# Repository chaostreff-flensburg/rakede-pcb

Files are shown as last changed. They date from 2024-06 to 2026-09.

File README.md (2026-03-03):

# ctfl-rakete-pcb

Converting this sticker desing into a PCB that lights up its flame and lighthouse top from the bottom side using some LEDs and a coin cell battery.

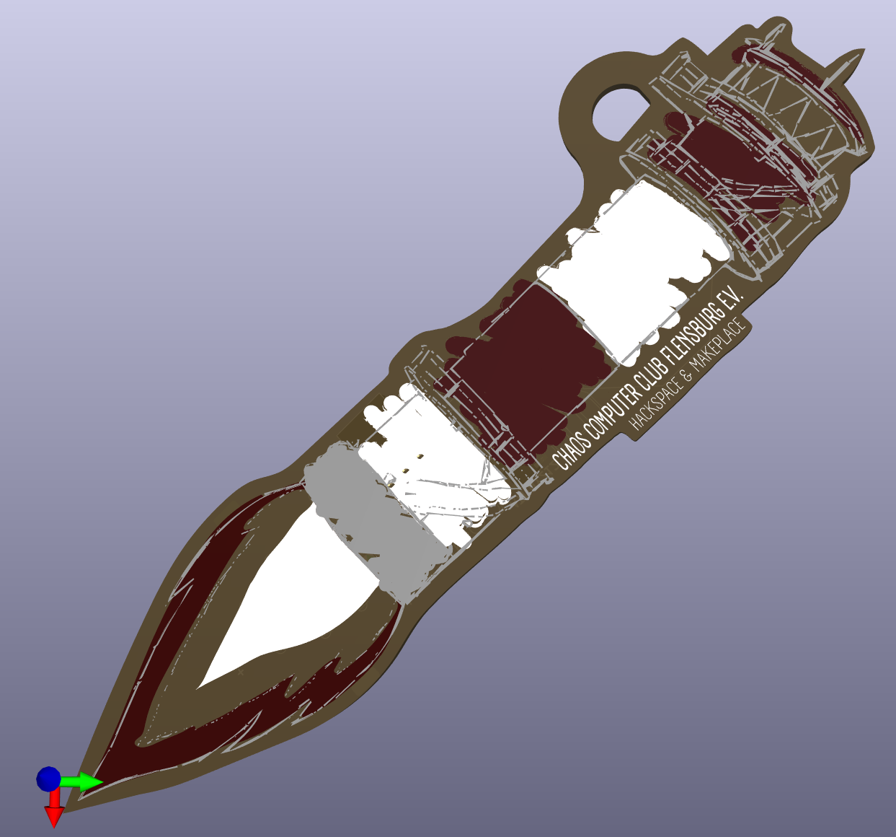
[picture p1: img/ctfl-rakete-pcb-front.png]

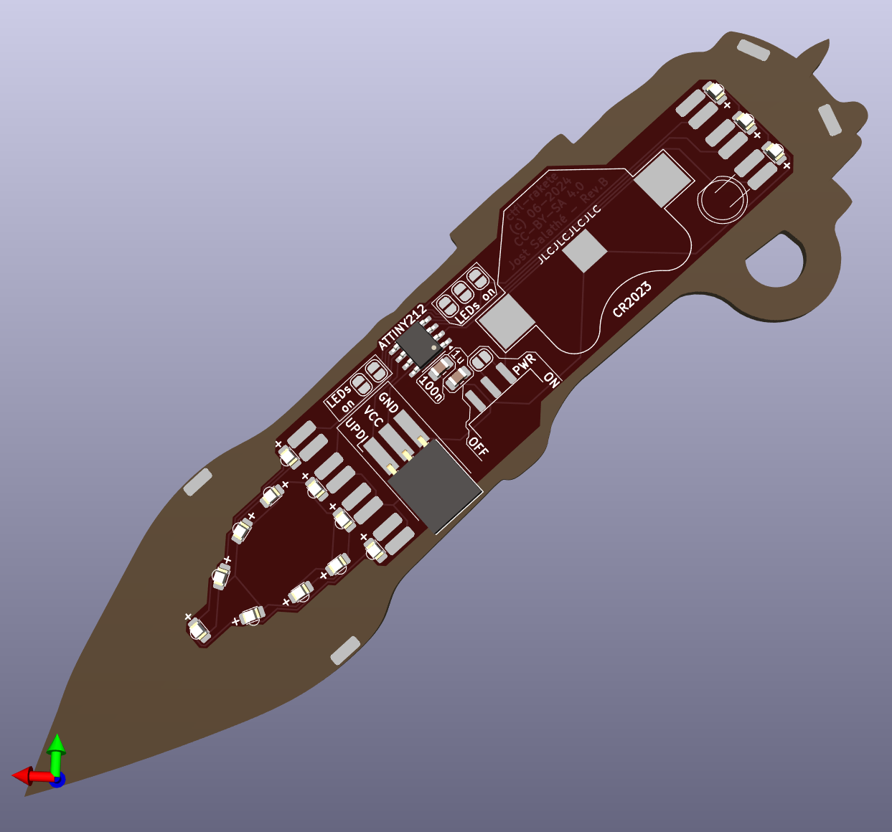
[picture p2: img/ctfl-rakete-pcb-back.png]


## Implementing the colors

Produce the PCBs with **red solder mask** and **white Silkscreen**.

| color | objects | pcb layers present | notes |
| --- | --- | --- | --- |
| white | background |  | considering the background to be transparent |
| white | w_flame | F.Cu, F.Silkscreen |  |
| yellow | y_flame, y_light | none | blank FR4 should give a nice translucent yellow |
| red | r_flame | F.Mask | only red solder mask should give a nice translucent red |
| red | r_tower, r_top, r_roof | F.Mask, f.Cu | with the copper underneath, the red solder mask should appear darker than at the flame |
| light grey | w_base, w_tower | F.Cu, F.Silkscreen |  |
| dark grey | g_base | F.Cu | not differentiated from black outlines |
| black | b_contours, b_name | F.Cu, F.Mask | only copper coated with tin should give a nice contouring contrast |

### Extracting solder mask geometry (F.Mask) from the complete SVG file

In KiCAD the solder mask is expressed as an exclusion mask from the usually all present solder mask coverage.
Meaning that you define geometry where you want solder mask NOT to be.

So the gemonetry we import into KiCAD has to be the negative of the red parts of our logo.

Additionally the solder mask has to back up the silkscreen so that negative image also has to include our white parts.

I concrete terms we need to perform the following steps on our yource vector grapfics to get the desired F.Mask geometry:
1. Delete the yellow lighthous part at the top because it is clipped by all surrounding parts and itself does not clip any other.
1. Combine the white and the red flame part into one.
1. Subtract the yellow flame part from the formerly combined rest of the flame.
1. Also subtract the dark grey socket part from the remaining flame.
1. Combine all remaining red and white parts.
1. Subtract the black outlines which shall poke through the solder mask and the silk screen. Now we have our positive image of the solder mask we want (plus the outline which we also want for positioning).
1. Duplicate the outline and move the duplicate below our solder mask positive.
1. Subtract the positive from the duplicate of the outline.
1. Save as new SVG file (`F.Mask.svg`)
1. Now you can import the SVG file to the appropriate layer in the pcb layout while scaling it by **1.85**.

## Part sourcing

| cnt THT | cnt THT-uC | cnt SMD | reference | title | reichelt.de | mouser.de |
| --- | --- | --- | --- | --- | --- | --- |
| 1 | 1 | 1 | BT1 | battery clip | [KZH 20SMD](https://www.reichelt.de/knopfzellenclip-fuer-20-mm-smd-kzh-20smd-p56574.html) | [534-3034](https://www.mouser.de/ProductDetail/Keystone-Electronics/3034?qs=LDXARy4xNQtGYr6pIAv90A%3D%3D) |
| 1 | 1 | 1 | SW1 | power switch | [SS SMD402](https://www.reichelt.de/schiebeschalter-1x-um-liegend-smd-ss-smd402-p112181.html) | [MSS-102545-14A-V-SMT](https://www.mouser.de/ProductDetail/CUI-Devices/MSS-102545-14A-V-SMT?qs=DRkmTr78QARl%2FtwuH8uRQg%3D%3D) |
| 0 | 1 | 1 | U1 | microcontroller | [ATTINY212](https://www.reichelt.de/8-bit-attiny-avr-risc-mikrocontroller-2-kb-20-mhz-soic-8-attiny212-ssn-p335520.html) | [ATTINY212-SSN](https://www.mouser.de/ProductDetail/Microchip-Technology/ATTINY212-SSN?qs=3HJ2avRr9PJX8cJeG3zkDw%3D%3D) |
| 0 | 0 | 14 | D? | SMD LEDs | - | [859-LTW-220DS5](https://www.mouser.de/ProductDetail/Lite-On/LTW-220DS5?qs=xb8aMrBSZRKaoLOPaZYE%252BQ%3D%3D) or [XIASONGXIN LIGHT - Side SMD 0805 (choose warm white)](https://de.aliexpress.com/item/32890300371.html) |
| 7 | 7 | 0 | D? | 5mm LEDs | [EVERLIGHT 334-15/X1C5-6QSA/EU](https://www.reichelt.de/led-5-mm-bedrahtet-warmweiss-7150-mcd-50--led-el-5-7150ww-p164207.html) | [941-C512AWNSCZ0B0152](https://www.mouser.de/ProductDetail/Cree-LED/C512A-WNS-CZ0B0152?qs=xEJ61ozf1a3Ja%252B55bf1fHw%3D%3D) |
| 0 | 1 | 1 | J1 | programming header (break off 3 of 50) | - | [437-8018305040001101](https://www.mouser.de/ProductDetail/Preci-dip/801-83-050-40-001101?qs=KBM%2FMdeLKegYqxBCoh54QQ%3D%3D) |
| 0 | 1 | 1 | C1 | 0805 capacitor 100 nF | - | [80-C0805C104J5R](https://www.mouser.de/ProductDetail/KEMET/C0805C104J5RACTU?qs=gbgtKHXraGH15GhoNPXHBg%3D%3D) |
| 0 | 1 | 1 | C3 | 0805 capacitor 1 uF | - | [963-UMK212B7105KG-T](https://www.mouser.de/ProductDetail/TAIYO-YUDEN/UMK212B7105KG-T?qs=PzICbMaShUdi76GLXMVYcA%3D%3D) |

## Default firmware

The directory `defaultFirmware` holds an Arduino sketch that is meant to be used with the [megaTinyCore](https://github.com/SpenceKonde/megaTinyCore) board support package for Arduino and can then be uploaded using a programmer like [SerialUPDI](https://github.com/wagiminator/AVR-Programmer/tree/master/SerialUPDI_Programmer), e.g. the [Adafruit UPDI Friend](https://learn.adafruit.com/adafruit-updi-friend).

Make sure to select the correct Chip in Arduino under `Tools -> Chip -> ATtiny212`, the correct Programmer under `Tools -> Programmer -> SerialUPDI - 230400 baud` (probably, depending on what you have) as well as the correct clock source under `Tools -> Clock -> "5 MHz internal"`

The logo on the PCB and the blinking pattern are based on the [lighthouse Kalkgrund](https://www.deutsche-leuchtfeuer.de/ostsee/kalkgrund.html).

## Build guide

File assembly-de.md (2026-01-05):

# Allgemeine Tips

## Ein Anschluss nach dem Anderen

Es bietet sich an, bei jedem Bauteil folgendermaßen vorzugehen:
- Erst ein einzelnes Lötpad für dieses Bautie vor-verzinnen
  - Dafür die Spitze des Lötkolbens mit etwas Druck so an die zu verzinnende Fläche legen, dass noch genug Platz ist, um das Lot direkt zum heißen Lötpad zu führen
- Das Bauteil (bei Bedarf mit einer Pinzette) korrekt positionieren, sodass der eine Anschluss in dem frisch aufgebrachten Lot sitzt
- Den Lötkolben wegziehen und das Bauteil noch einen Augenblick fixieren, bis das Lot erkalet ist.

So kann jetzt noch, falls erforderlich, die Position des Bauteils an dieser einen Lötstelle korrigiert werden.

Bist du mit dem Sitz des Bauteils auf dem zugehörigen Footbrint zufrieden, verlötest du den/die übrigen Anschluss(-üsse) des Bauteils.

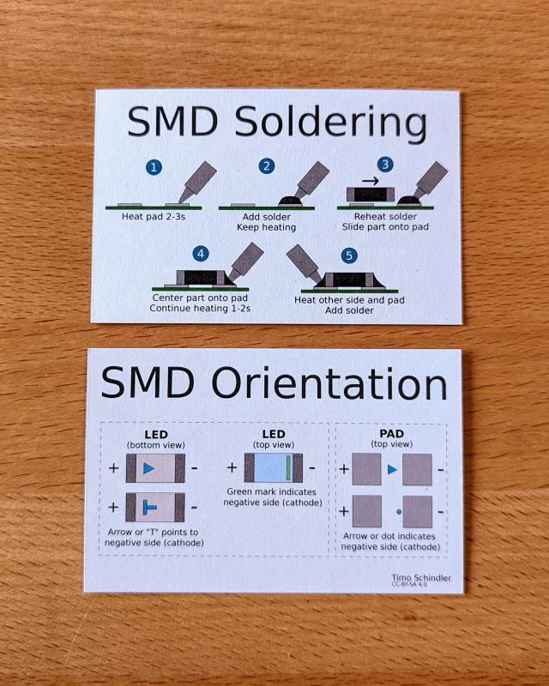
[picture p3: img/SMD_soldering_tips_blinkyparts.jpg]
SMD Löttips von von Blinkyparts


## Von Klein nach Groß und/oder von Innen nach Außen

Arbeite von innen nach außen und von kleinen Bauteilen zu großen. Es mag zwar verlockend sein, mit den großen, einfach zu lötenden Teilen anzufangen, aber üblicherweise sind sie dir dann später im Weg.

# Schwierigkeitsgrad 1: Mit Beinchen

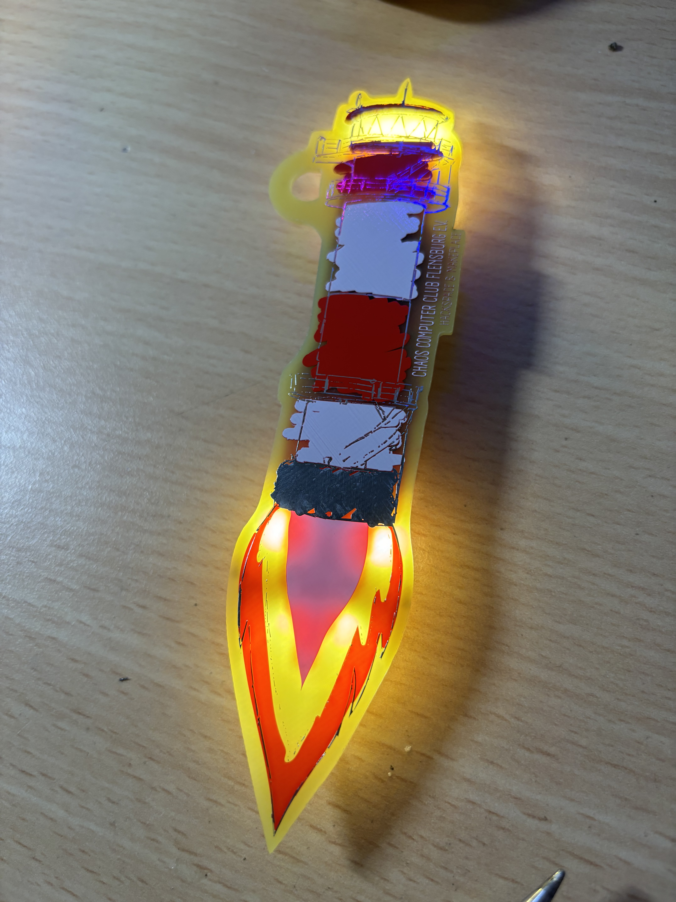
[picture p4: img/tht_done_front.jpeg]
fertig


## Benötigte Bauteile

In empfohlener Bestückreihenfolge sortiert:

| Nummer | Anzahl |Name |
| --- | --- | --- |
| 1 | 1 | Platine |
| 2 | 1 | Schalter |
| 3 | 1 | Batteriehalter |
| 4 | 7 | weiße 5mm LED (ca. 3V)  |
| 5 | 1 | CR2032 Knopfzellenbatterie |

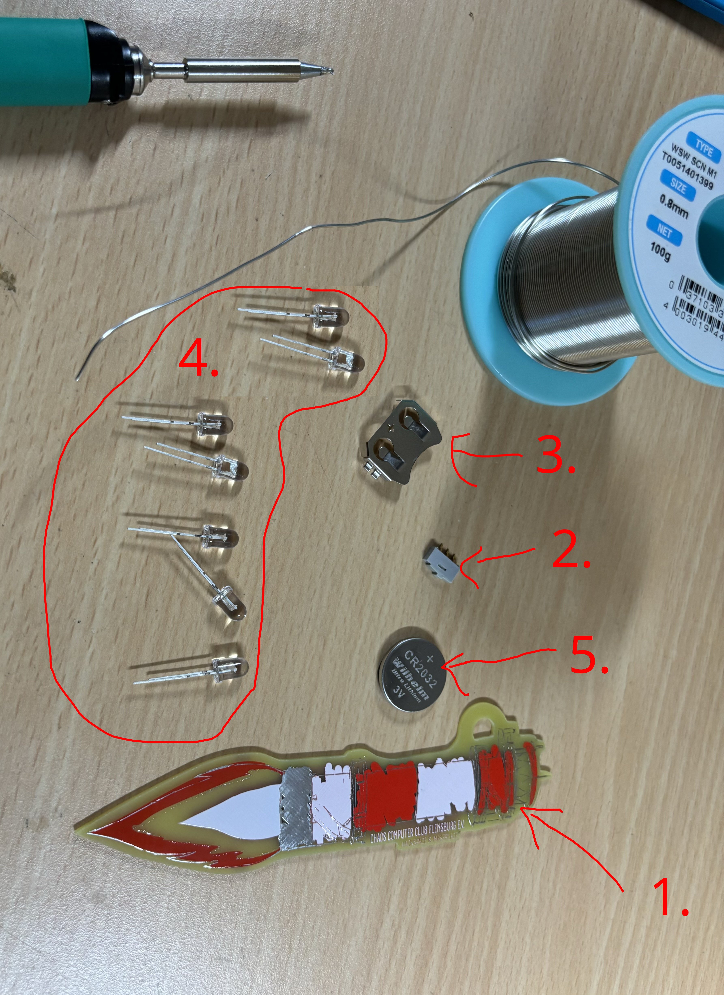
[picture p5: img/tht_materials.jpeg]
THT Material


## Montage

Solange die Platine noch so schön leer ist, können die 5 Lötbrücken geschlossen werden, die die LEDs dauerhaft leuchten lassen, solange der Schalter an ist. Sie sind markiert mit der Beschriftung "LEDs on".

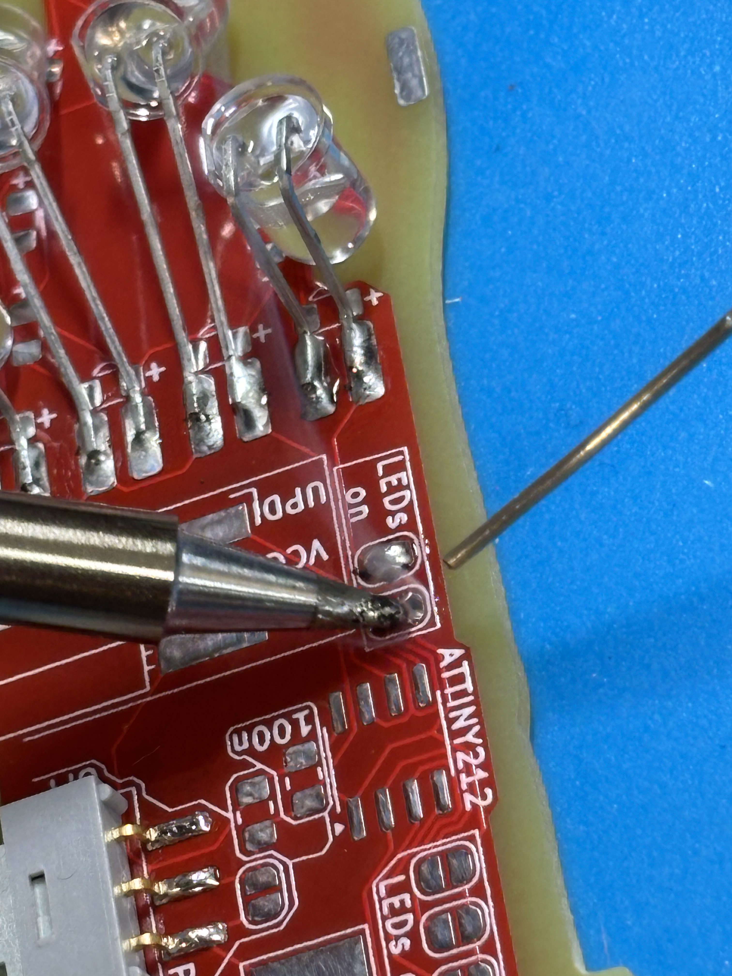
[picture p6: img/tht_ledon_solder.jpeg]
Lötbrücken


Als erstes Bauteil sollte bei dieser Variante der Schalter montiert werden.

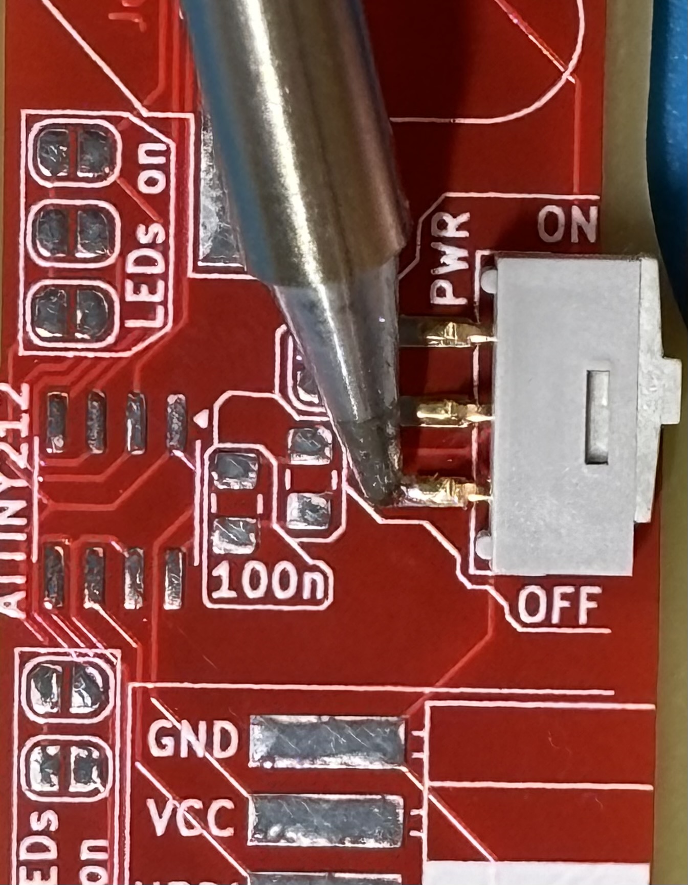
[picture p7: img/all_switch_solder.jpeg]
Schalter


Damit die Knopfzelle guten Kontakt hat, sollte noch etwas Zinn auf den negativen Batteriekontakt auf der Platine gegeben werden. Aber auch nicht zu viel, sonst sitzt die Batterie nachher zu stramm.

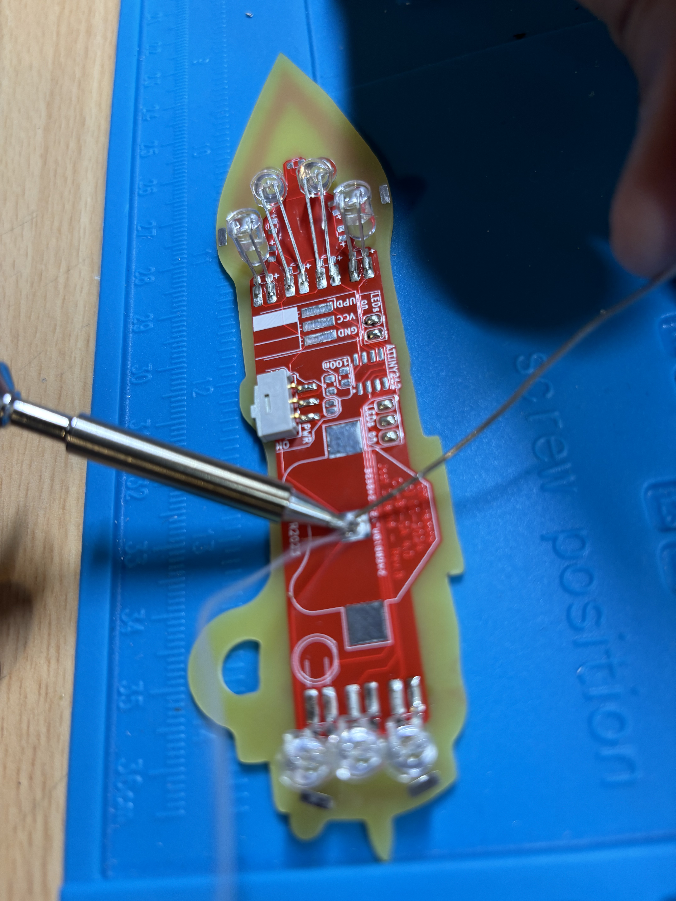
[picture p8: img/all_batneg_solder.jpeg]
Batteriekontakt Minus


Danach kann der Batteriehalter dadrübergelötet werden. Hierbei am besten die beiden Verbindungen zwischen Lötpads und Batteriehalter richtig mit Zinn fluten, damit die mechanische Klemmkraft der Batterie den Halter später nicht abreißt.

Auf dem folgenden Bild sind die Stellen etwas zu sparsam ausgestattet:

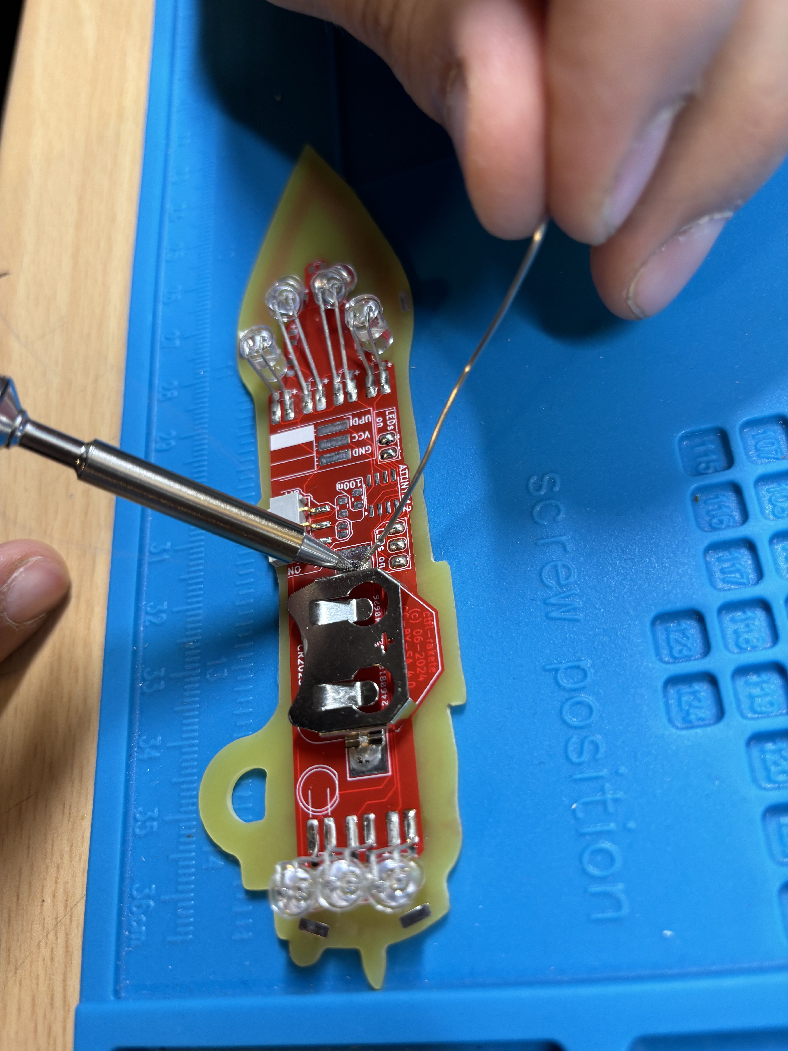
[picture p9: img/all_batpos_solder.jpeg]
Batteriehalter


Jetzt gibt es Interpretationsspielraum, wie du die LEDs am liebsten montieren magst.

Hauptsache ist, dass du die beiden Beinchen richtig verbindest.

Das längere Beinchen ist Plus (auf der Platine mit "+" markiert), das kürzere Beinchen Minus. Aber selbst nachdem du die Beinchen gekürzt hast, kannst du das noch zuordnen, weil das Gehäuse der LED an der Minusseite etwas abgeflacht ist.

Wenn du eine LED falsch herum einbaust, leuchtet sie einfach nicht. Versuche dann, sie andersherum einzubauen.

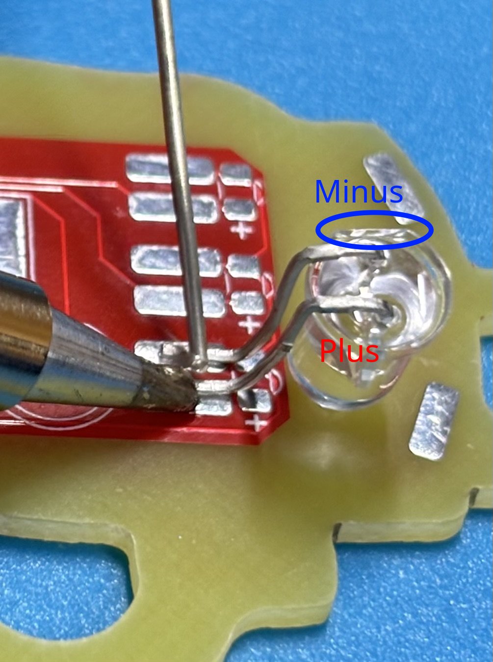
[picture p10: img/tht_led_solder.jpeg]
LED verlöten


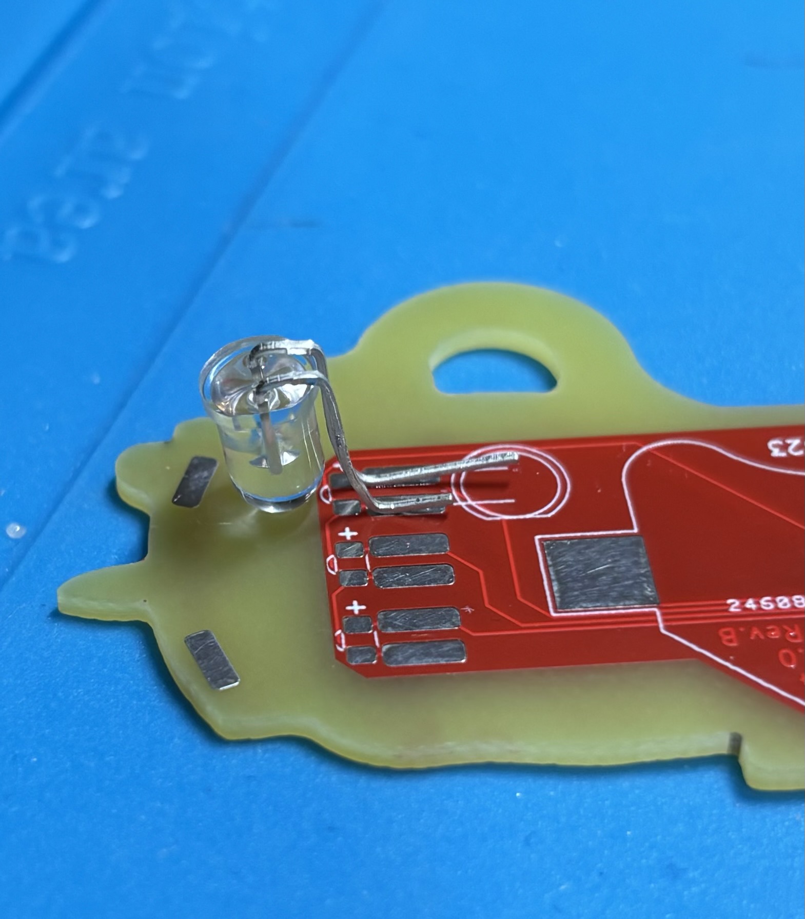
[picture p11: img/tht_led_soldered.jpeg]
LED verlötet


So könnten das dann zum Beispiel aussehen:

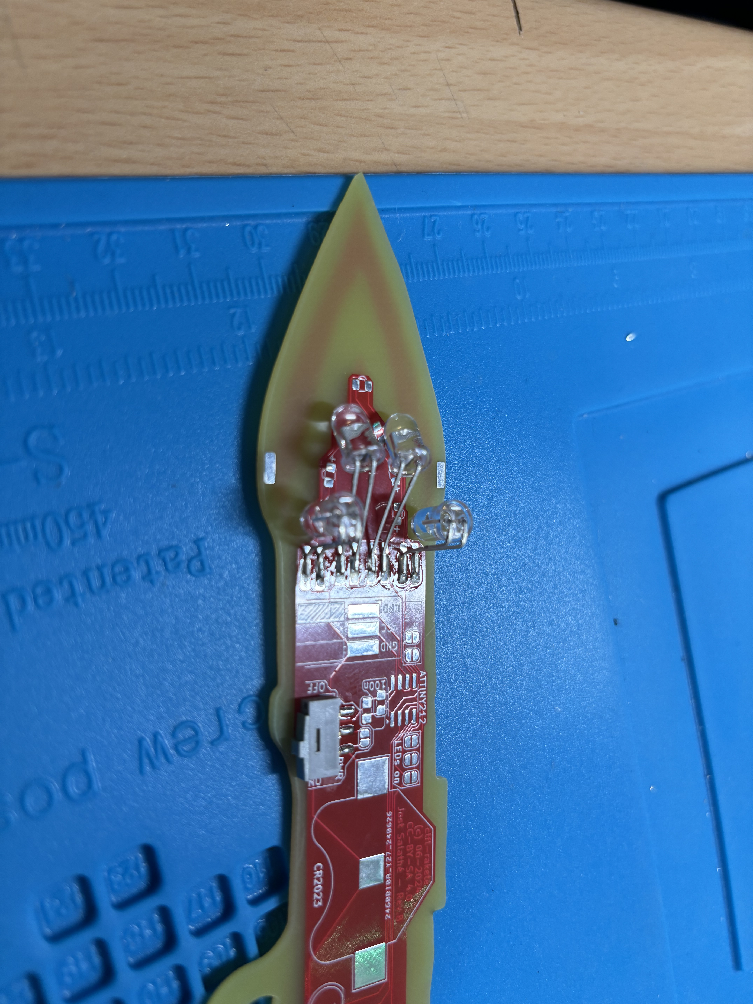
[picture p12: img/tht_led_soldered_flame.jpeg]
LEDs Flamme verlötet


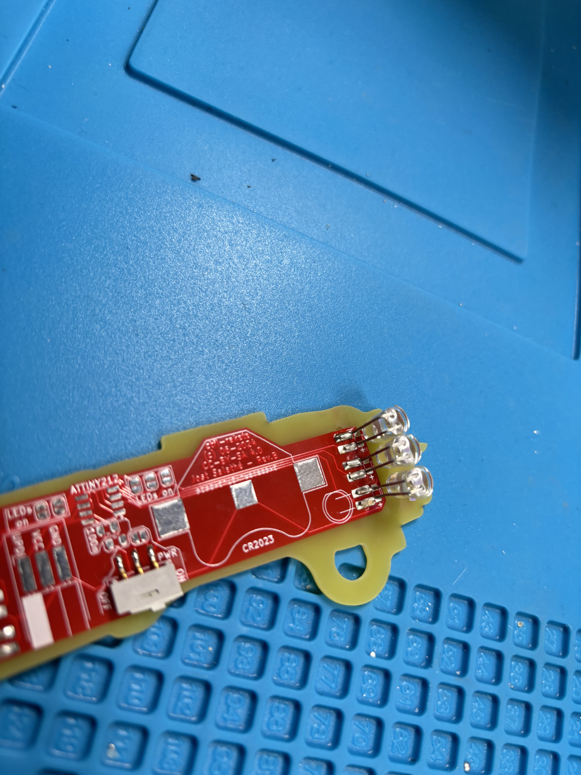
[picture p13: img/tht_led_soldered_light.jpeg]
LEDs oben verlötet


# Schwierigkeitsgrad 2: Mit Beinchen und Mircocontroller

## Benötigte Bauteile

In empfohlener Bestückreihenfolge sortiert:

| Nummer | Anzahl |Name |
| --- | --- | --- |
| 1 | 1 | Platine |
| 2 | 1 | Entkoppelkondensator 100 nF |
| 3 | 1 | Stützkondensator 1 uF |
| 1 | 1 | ATtiny212 Mircocontroller |
| 5 | 1 | Schalter |
| 6 | 1 | Programmieranschluss (UPDI) |
| 7 | 1 | Batteriehalter |
| 8 | 7 | weiße 5mm LED (ca. 3V)  |
| 9 | 1 | CR2032 Knopfzellenbatterie |

SMTHT Material

## Montagehinweise

Zur Montage des Schwierigkeitsgrads 1 ändert sich folgendes:
- Es wird zusätzlich ein Microcontroller mit ein paar Hilfsbauteilen aufgelötet
  - 2 SMD-Kondensatoren zur Stabilisierung der Controllerversorgung
  - Programmieranschluss
- Die 5 Lötbrücken werden nicht gesetzt - ihre Aufgabe wird von dem Microcontroller übernommen

Die Orientierung des Microcontrollers sollte unbedingt beachtet werden.
Auf dem Controllergehäuse ist ein Punkt bei Pin 1.
Passend dazu ist auf der Platine an Pin 1 ein kleiner Pfeil.

ATTINY orientation

Die beiden Kondensatoren sind parallel geschaltet und dienen nur zur Stabilisierung der Versorgungsspannung des Microcontrollers.
Es ist nicht so wichtig, welcher von beiden wo sitzt.
Und falls einer oder beide verloren gehen, ist das auch nicht so schlimm.

# Schwierigkeitsgrad 3: Beinfrei

## Benötigte Bauteile

In empfohlener Bestückreihenfolge sortiert:

| Nummer | Anzahl |Name |
| --- | --- | --- |
| 1 |  1 | Platine |
| 2 |  1 | Entkoppelkondensator 100 nF |
| 3 |  1 | Stützkondensator 1 uF |
| 1 |  1 | ATtiny212 Mircocontroller |
| 5 |  1 | Schalter |
| 6 |  1 | Programmieranschluss (UPDI) |
| 7 | 14 | weiße SMD-LEDs (seitenleuchtend, ca. 3V)  |
| 8 |  1 | Batteriehalter |
| 9 |  1 | CR2032 Knopfzellenbatterie |

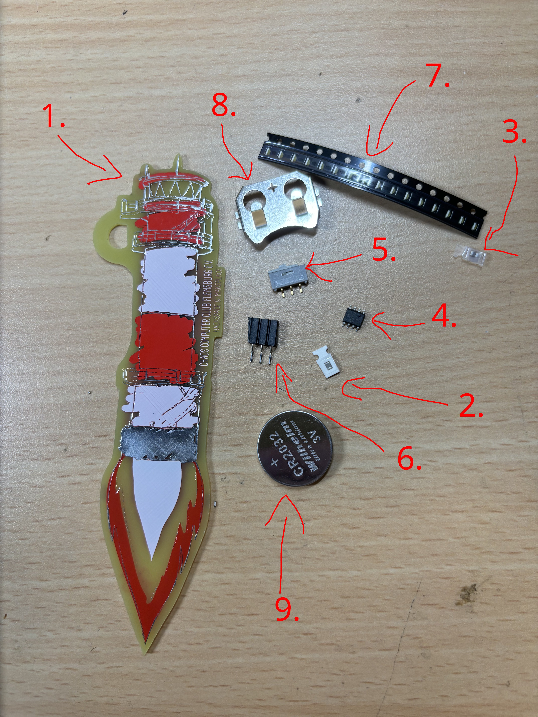
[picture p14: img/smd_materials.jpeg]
SMD Material


## Montagehinweise

Zur Montage des Schwierigkeitsgrads 2 ändert sich folgendes:
- die 7 5mm LEDs werden ersetzt durch 14 zur Seite leuchtende SMD-LEDs

Die Polarität der LEDs ist dabei unbedingt zu beachten:

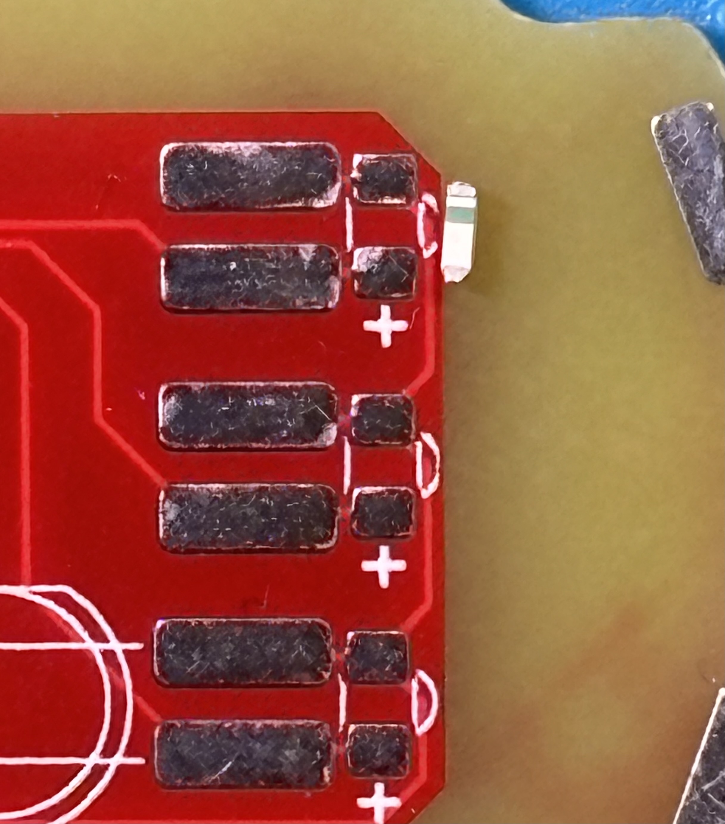
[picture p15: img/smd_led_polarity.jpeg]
SMD-LED Polarität


Verwende am besten eine Pinzette, um die LED in Position zu halten, während du die erste Seite festlötest:

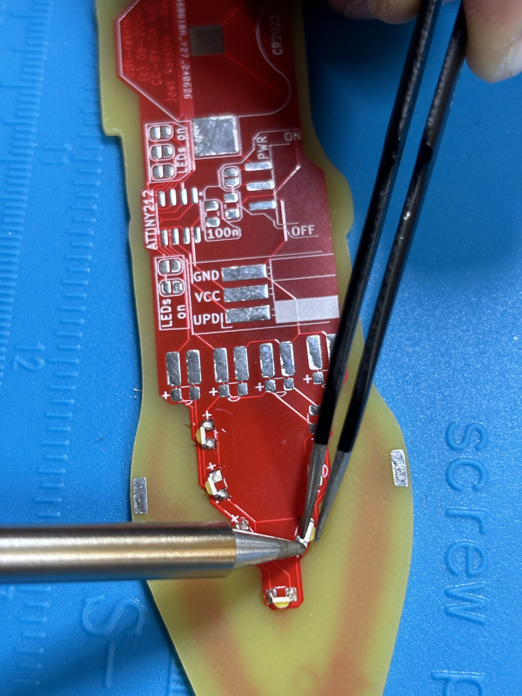
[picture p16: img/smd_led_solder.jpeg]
SMD-LED festlöten


Es werden 14 LEDs benötigt.
Da die kleinen LEDs leicht einmal verloren gehen, legen wir den Kits normalerweise 16 LEDs bei.

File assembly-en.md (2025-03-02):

# TBD

See [german version](assembly-de.md)...

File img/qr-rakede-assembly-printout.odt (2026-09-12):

How to solder the C3FL Rakede PCB

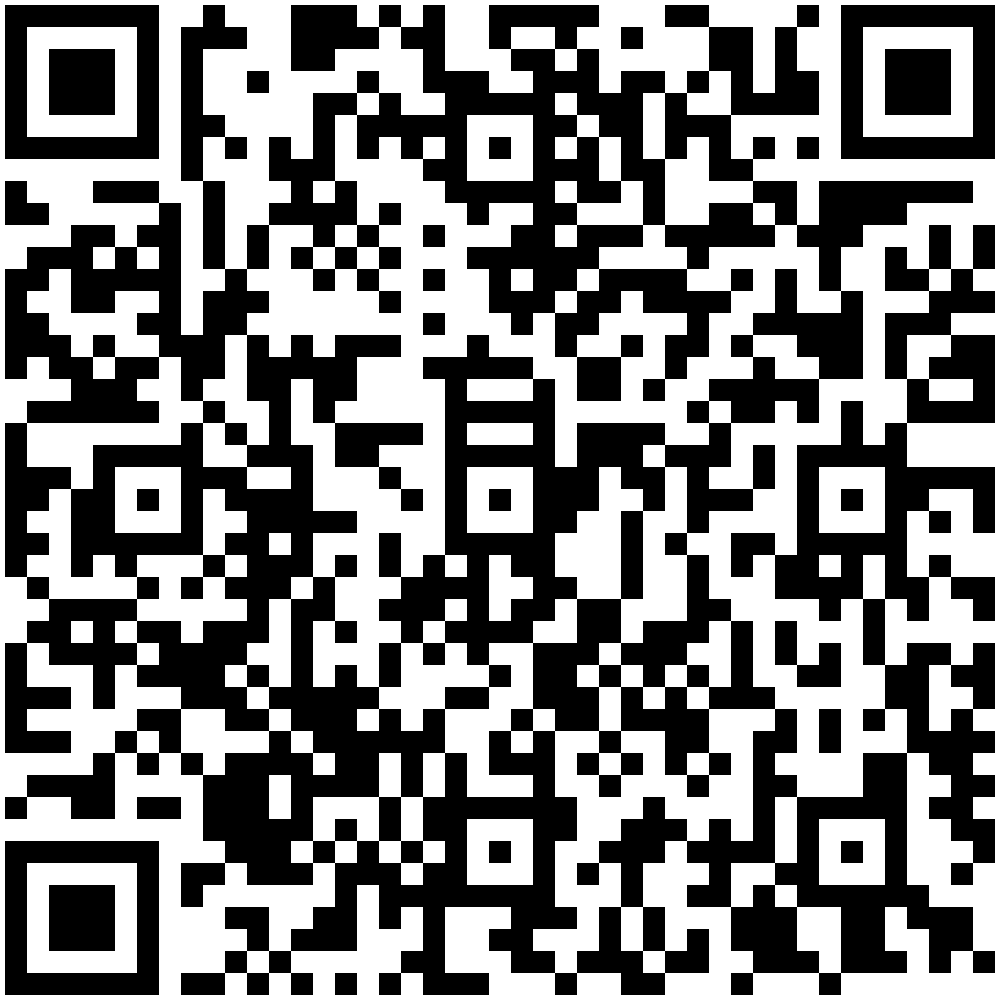
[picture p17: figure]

Wie man die C3FL Rakede PCB löded

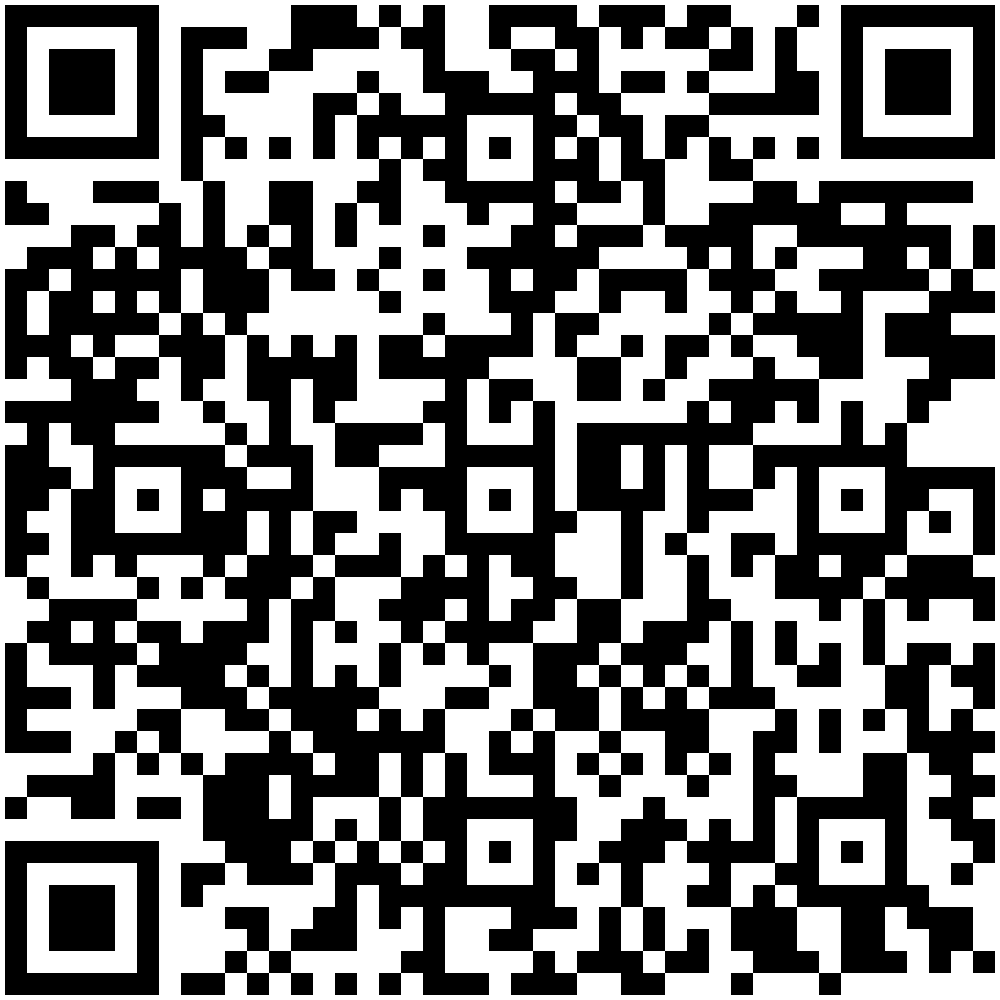
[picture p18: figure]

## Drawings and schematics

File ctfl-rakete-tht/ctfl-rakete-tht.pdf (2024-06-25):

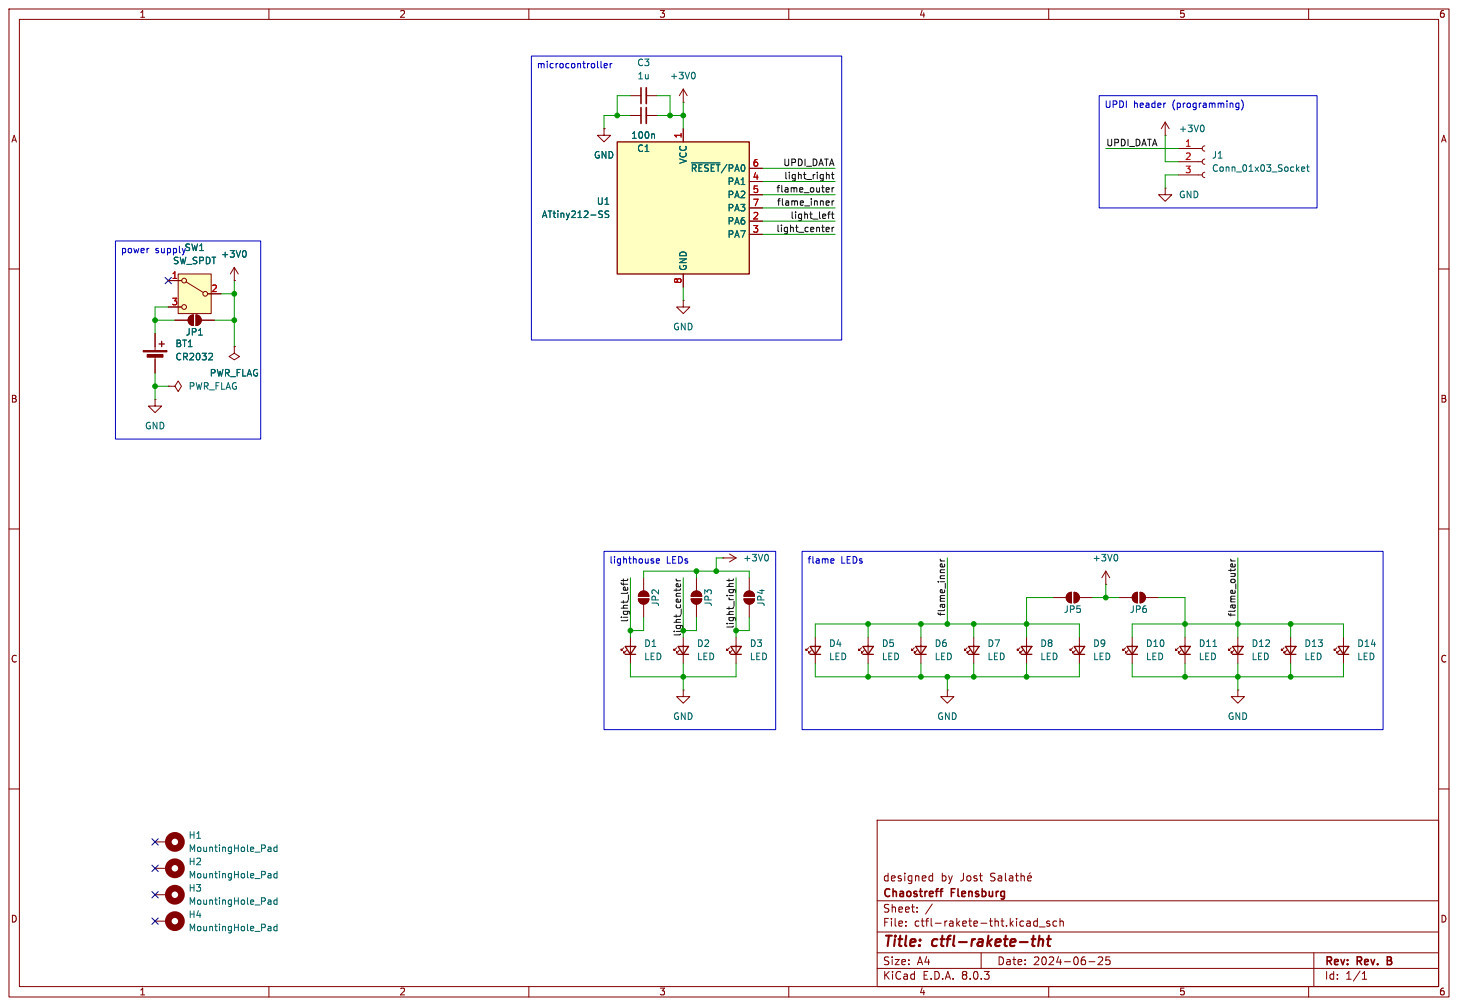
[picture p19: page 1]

flame LEDs power supply

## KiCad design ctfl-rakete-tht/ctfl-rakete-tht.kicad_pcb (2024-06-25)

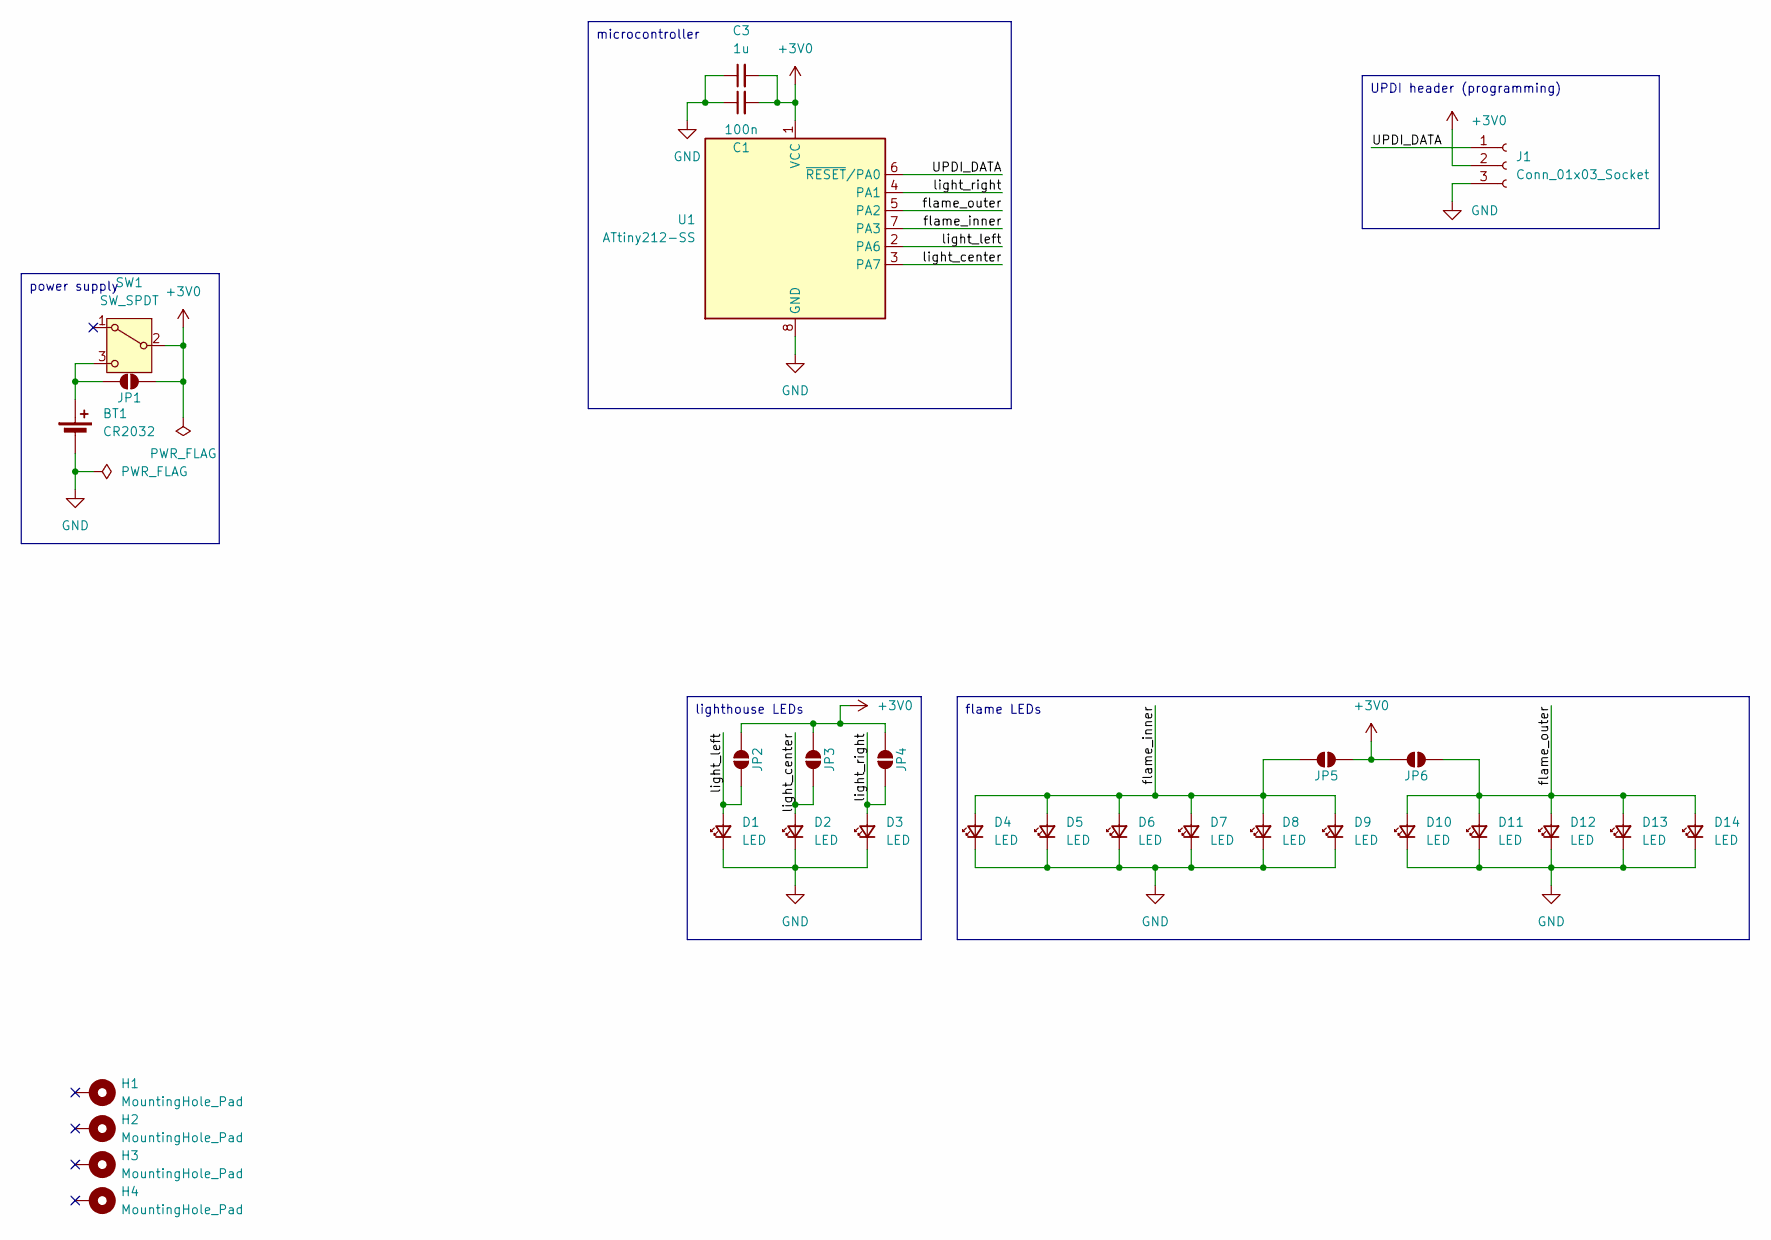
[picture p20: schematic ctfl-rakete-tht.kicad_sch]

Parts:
BT1: CR2032; BatteryHolder_Multicomp_BC-2001_1x2032
C1: 100n; C_0805_2012Metric_Pad1.18x1.45mm_HandSolder
C3: 1u; C_0805_2012Metric_Pad1.18x1.45mm_HandSolder
D1, D2, D3, D4, D5, D10, D11: LED; LED_combo_0805_5mmSMD_HandSolder
D6, D7, D8, D9, D12, D13, D14: LED; LED_0805_SMD_HandSolder
H1, H2, H3, H4: MountingHole_Pad; wire_pad
J1: Conn_01x03_Socket; PinSocket_1x03_P2.54mm_Horizontal_SMD
JP1, JP2, JP3, JP4, JP5, JP6: SolderJumper_2_Open; SolderJumper-2_P1.3mm_Open_RoundedPad1.0x1.5mm
SW1: SW_SPDT; SW_SPDT_ESP4020
U1: ATtiny212-SS; SOIC-8_3.9x4.9mm_P1.27mm

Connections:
+3V0: C1.2, C3.2, J1.2, JP1.2 (B), JP2.2 (B), JP3.2 (B), JP4.2 (B), JP5.2 (B), JP6.2 (B), SW1.2 (B), U1.1 (VCC)
/UPDI_DATA: J1.1, U1.6 (~RESET/PA0)
/flame_inner: D4.2 (A), D5.2 (A), D6.2 (A), D7.2 (A), D8.2 (A), D9.2 (A), JP5.1 (A), U1.7 (PA3)
/flame_outer: D10.2 (A), D11.2 (A), D12.2 (A), D13.2 (A), D14.2 (A), JP6.1 (A), U1.5 (PA2)
/light_center: D2.2 (A), JP3.1 (A), U1.3 (PA7)
/light_left: D1.2 (A), JP2.1 (A), U1.2 (PA6)
/light_right: D3.2 (A), JP4.1 (A), U1.4 (PA1)
GND: BT1.2 (-), C1.1, C3.1, D1.1 (K), D2.1 (K), D3.1 (K), D4.1 (K), D5.1 (K), D6.1 (K), D7.1 (K), D8.1 (K), D9.1 (K), D10.1 (K), D11.1 (K), D12.1 (K), D13.1 (K), D14.1 (K), J1.3, U1.8 (GND)
unnamed: BT1.1 (+), JP1.1 (A), SW1.3 (C)

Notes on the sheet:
flame LEDs
UPDI header (programming)
microcontroller
lighthouse LEDs
power supply

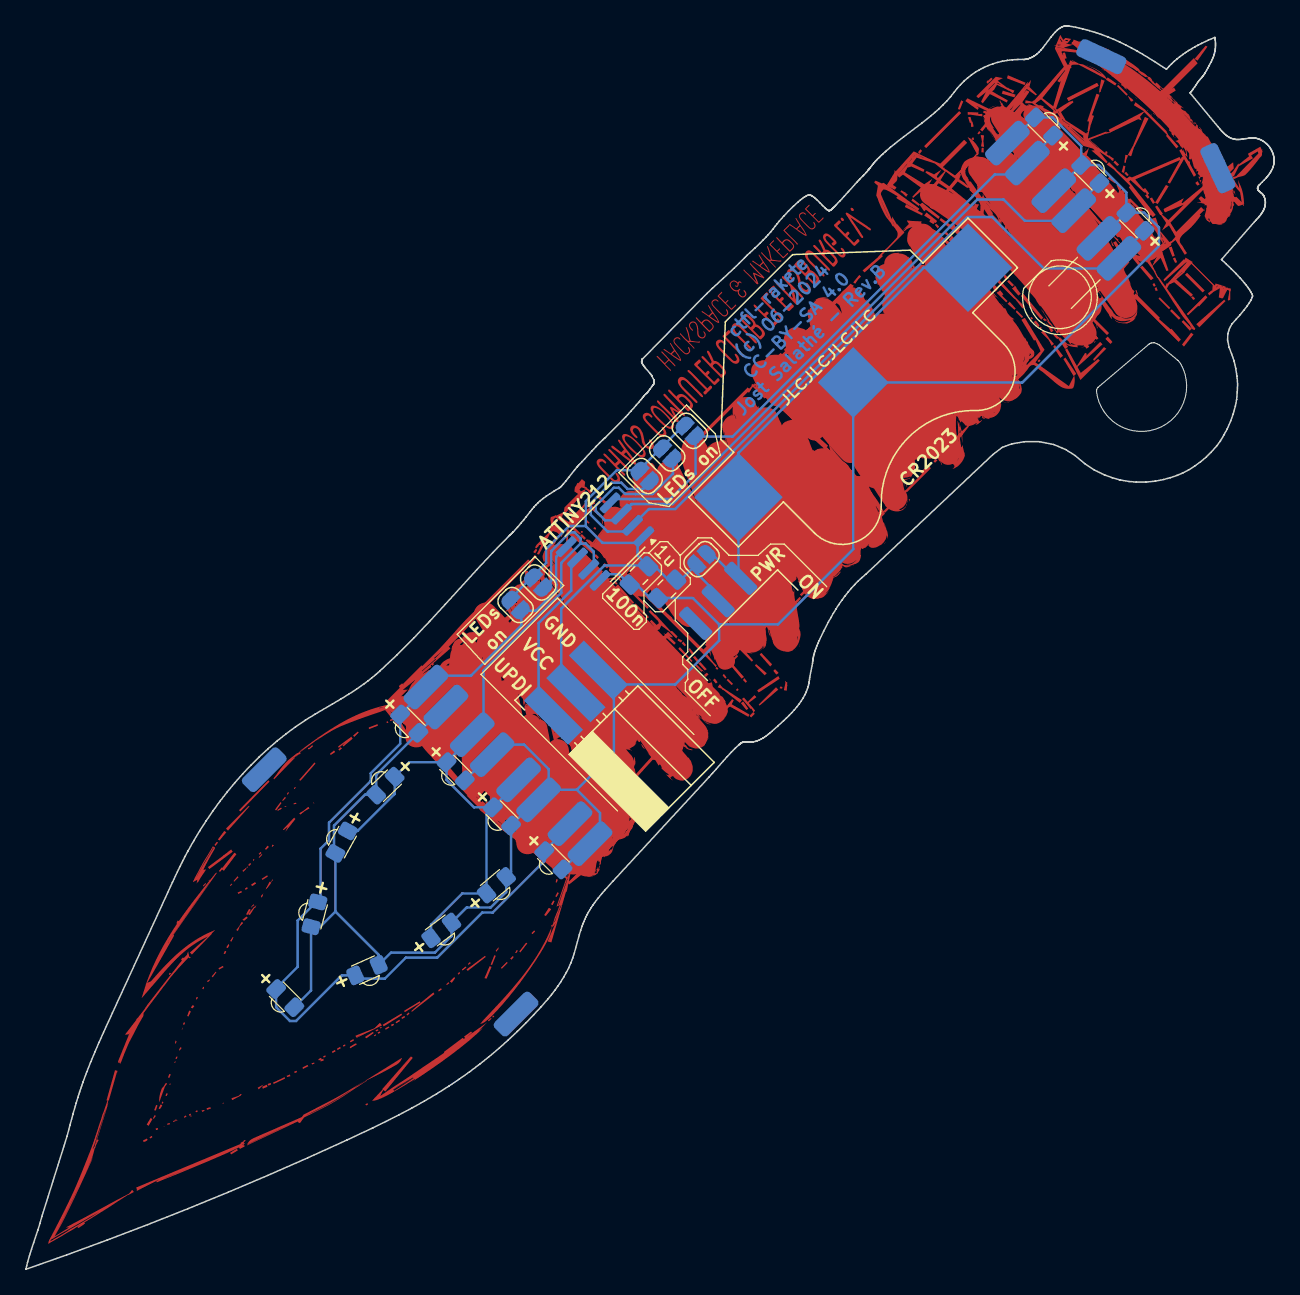
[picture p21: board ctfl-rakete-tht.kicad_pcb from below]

Board: 2 copper layers, 99.6 x 99.2 mm, 30 parts (30 on the bottom side), 9 nets.

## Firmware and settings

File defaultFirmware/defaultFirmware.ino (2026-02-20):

#include <avr/sleep.h>
enum {
  LedIndexLightL,
  LedIndexLightC,
  LedIndexLightR,
  LedIndexFlameI,
  LedIndexFlameO,
  LedIndexMax
};

const int ledPins[LedIndexMax] = {
  PIN_PA6, // LightL, no hard PWM
  PIN_PA7, // LightC
  PIN_PA1, // LightR
  PIN_PA3, // FlameI
  PIN_PA2  // FlameO
};

//const uint16_t VCC_LOW_CUTOFF_MV = 2800; // low voltage cutoff to protect Li-Ion cells
const uint16_t VCC_LOW_CUTOFF_MV = 2400; // low voltage cutoff to indicate that battery is really empty (NOT FOR Li-Ion!)
// following parameters result in roughly 10 mA on average (about 7 h runtime on a LIR2032H (70 mAh) until UVLO = 2.8 V)
const uint16_t VCC_DIMMING_LOW_END_MV = 2570; // inflection point of hyperbola
const uint32_t VCC_DIMMING_FACTOR = 80; // increase this value if you want the LEDs to be brighter
// following parameters result in roughly 20 mA on average (about 3.5 h runtime on a LIR2032H (70 mAh) until UVLO = 2.8 V)
//const uint16_t VCC_DIMMING_LOW_END_MV = 2570; // voltage above which globalBrightness is reduced to conserve energy
//const uint32_t VCC_DIMMING_FACTOR = 200; // increase this value if you want the LEDs to be brighter


// soft PWM using micros() with target frequency of 100 Hz
// results in a total resolution of 10.000 split into 100 global x 100 individual
const uint8_t GLOBAL_BRIGHTNESS_MAX = 250;
const uint8_t INDIVIDUAL_BRIGHTNESS_MAX = 40;
uint8_t globalBrightness = GLOBAL_BRIGHTNESS_MAX;
uint8_t ledBrightness[LedIndexMax] = {
  0,
  0,
  0,
  0,
  0
};


void setup() {
  for (int iLed = 0; iLed < LedIndexMax; iLed++) {
    pinMode(ledPins[iLed], OUTPUT);
    digitalWrite(ledPins[iLed], LOW);
  }

  analogReference(INTERNAL1V5); // set reference to the desired voltage, and set that as the ADC reference.
  analogReference(VDD); // Set the ADC reference to VDD. Voltage selected previously is still the selected, just not set as the ADC reference.
  uint16_t reading = analogRead(ADC_INTREF); //first reading might be inaccturate
  (void) reading; // to suppress unused variable warning

  // while(1) for (int iLed = 0; iLed < LedIndexMax; iLed++) {
  //   digitalWrite(iLed, HIGH);
  //   delay(1900);
  //   digitalWrite(iLed, LOW);
  //   delay(100);
  // }
}

void adaptToVcc() {
  const uint32_t intermediate = 1023ul * 1500;
  uint16_t reading = analogRead(ADC_INTREF);
  uint16_t vccMv = intermediate / reading;
  if (vccMv < VCC_LOW_CUTOFF_MV) {
    for (int iLed = 0; iLed < LedIndexMax; iLed++) {
      digitalWrite(ledPins[iLed], LOW);
      pinMode(ledPins[iLed], INPUT);
    }
    set_sleep_mode(SLEEP_MODE_PWR_DOWN);
    sleep_enable();
    sleep_cpu();
  }
  //set globalBrightness according to Vcc
  if (vccMv > VCC_DIMMING_LOW_END_MV) {
    // antiproportional relation between Vcc and globalBrightness
    uint16_t brightness = GLOBAL_BRIGHTNESS_MAX * VCC_DIMMING_FACTOR
                          / (vccMv - VCC_DIMMING_LOW_END_MV);

    if (brightness > GLOBAL_BRIGHTNESS_MAX) {
      globalBrightness = GLOBAL_BRIGHTNESS_MAX;
    } else {
      globalBrightness = brightness;
    }
  } else {
    globalBrightness = GLOBAL_BRIGHTNESS_MAX;
  }
}


// animation timing like 'Leuchtturm Kalkgrund':
// (see https://www.deutsche-leuchtfeuer.de/ostsee/kalkgrund.html)
// Iso WRG 8 s   [4+(4)]
// 8 seconds for one rotation
// 4 seconds on, 4 senconds off
// fading from right to left (simulating clockwise rotation)

void animateLightBlip(uint16_t msSinceStart) {
  if (msSinceStart < 100) {
    ledBrightness[LedIndexLightR] = INDIVIDUAL_BRIGHTNESS_MAX;
    ledBrightness[LedIndexLightC] = 0;
    ledBrightness[LedIndexLightL] = 0;
  } else if (msSinceStart < 200) {
    ledBrightness[LedIndexLightR] = INDIVIDUAL_BRIGHTNESS_MAX;
    ledBrightness[LedIndexLightC] = INDIVIDUAL_BRIGHTNESS_MAX;
    ledBrightness[LedIndexLightL] = 0;
  } else if (msSinceStart < 4000) {
    ledBrightness[LedIndexLightR] = INDIVIDUAL_BRIGHTNESS_MAX;
    ledBrightness[LedIndexLightC] = INDIVIDUAL_BRIGHTNESS_MAX;
    ledBrightness[LedIndexLightL] = INDIVIDUAL_BRIGHTNESS_MAX;
  } else if (msSinceStart < 4100) {
    ledBrightness[LedIndexLightR] = 0;
    ledBrightness[LedIndexLightC] = INDIVIDUAL_BRIGHTNESS_MAX;
    ledBrightness[LedIndexLightL] = INDIVIDUAL_BRIGHTNESS_MAX;
  } else if (msSinceStart < 4200) {
    ledBrightness[LedIndexLightR] = 0;
    ledBrightness[LedIndexLightC] = 0;
    ledBrightness[LedIndexLightL] = INDIVIDUAL_BRIGHTNESS_MAX;
  } else {
    ledBrightness[LedIndexLightR] = 0;
    ledBrightness[LedIndexLightC] = 0;
    ledBrightness[LedIndexLightL] = 0;
  }
}

void animateLight(unsigned long nowUs) {
  const uint32_t ANIMATION_INTERVAL_US = 8000ul * 1000;

  static unsigned long animationStartUs = 0;
  
  uint32_t usSinceAnimationStart = nowUs - animationStartUs;
  if (usSinceAnimationStart > ANIMATION_INTERVAL_US) {
    animationStartUs += ANIMATION_INTERVAL_US;
    usSinceAnimationStart -= ANIMATION_INTERVAL_US;
  }

  animateLightBlip(usSinceAnimationStart / 1000);
}


void animateFlame(unsigned long nowUs) {
  const uint8_t PWM_DIM = INDIVIDUAL_BRIGHTNESS_MAX/3*2;
  const uint8_t PWM_BRIGHT = INDIVIDUAL_BRIGHTNESS_MAX;
  const uint16_t FRAMETIME_US = 60ul * 1000;
  unsigned long nowFrame = nowUs / FRAMETIME_US;
  static unsigned long lastFrame = 0;

  if (nowFrame != lastFrame) {
    switch (nowFrame % 3) {
    case 0:
      ledBrightness[LedIndexFlameI] = PWM_DIM;
      ledBrightness[LedIndexFlameO] = PWM_DIM;
      break;

    case 1:
      ledBrightness[LedIndexFlameI] = PWM_BRIGHT;
      ledBrightness[LedIndexFlameO] = PWM_DIM;
      break;

    case 2:
    default:
      ledBrightness[LedIndexFlameI] = PWM_DIM;
      ledBrightness[LedIndexFlameO] = PWM_BRIGHT;
      break;
    }

    lastFrame = nowFrame;
  }
}


void loop() {
  //drive LEDs
  const uint16_t PULSE_INTERVAL_US = static_cast<uint16_t>(INDIVIDUAL_BRIGHTNESS_MAX) * static_cast<uint16_t>(GLOBAL_BRIGHTNESS_MAX);

  static unsigned long pulseStartUs = 0;
  static bool needReCalculate = true;

  uint16_t usSincePulseStart = static_cast<uint16_t>(micros() - pulseStartUs);

  if (usSincePulseStart >= PULSE_INTERVAL_US) {
    // advance pulseStart_us, calculate animation and turn on LEDS if required 
    pulseStartUs += PULSE_INTERVAL_US;
    needReCalculate = true;

    if (globalBrightness > 0) {
      if (ledBrightness[LedIndexLightL] > 0)
        digitalWriteFast(ledPins[LedIndexLightL], HIGH);
      if (ledBrightness[LedIndexLightC] > 0)
        digitalWriteFast(ledPins[LedIndexLightC], HIGH);
      if (ledBrightness[LedIndexLightR] > 0)
        digitalWriteFast(ledPins[LedIndexLightR], HIGH);
      if (ledBrightness[LedIndexFlameI] > 0)
        digitalWriteFast(ledPins[LedIndexFlameI], HIGH);
      if (ledBrightness[LedIndexFlameO] > 0)
        digitalWriteFast(ledPins[LedIndexFlameO], HIGH);
    }
  } else {
    if (needReCalculate && usSincePulseStart >= (PULSE_INTERVAL_US / 2)) {
      needReCalculate = false;

      adaptToVcc();
      animateLight(pulseStartUs);
      animateFlame(pulseStartUs);
    }
    // turn off LEDs according to their brightness
    if (usSincePulseStart > ledBrightness[LedIndexLightL] * globalBrightness)
      digitalWriteFast(ledPins[LedIndexLightL], LOW);
    if (usSincePulseStart > ledBrightness[LedIndexLightC] * globalBrightness)
      digitalWriteFast(ledPins[LedIndexLightC], LOW);
    if (usSincePulseStart > ledBrightness[LedIndexLightR] * globalBrightness)
      digitalWriteFast(ledPins[LedIndexLightR], LOW);
    if (usSincePulseStart > ledBrightness[LedIndexFlameI] * globalBrightness)
      digitalWriteFast(ledPins[LedIndexFlameI], LOW);
    if (usSincePulseStart > ledBrightness[LedIndexFlameO] * globalBrightness)
      digitalWriteFast(ledPins[LedIndexFlameO], LOW);
  }
}

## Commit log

2024-03-10 added sticker svg and empty kicad project
    [ctfl-rakete-tht.kicad_pcb, ctfl-rakete-tht.kicad_sch]
2024-03-10 removed lock files from kicad project - we don't want to track those
2024-03-10 added a max size frame into pcb design
    [ctfl-rakete-tht.kicad_pcb]
2024-03-10 merged a lot of single paths into large paths to simplify the svg import into KiCad
2024-03-10 added ideas about how to implement the different colors of the original design on PCB
2024-03-19 added dedicate svg files for pcb layers Edge.Cuts, F.Cu and F.Mask, but they need additional fiducials...
2024-04-23 added silkscreen svg file and imported all into layout
    [ctfl-rakete-tht.kicad_pcb]
2024-05-04 added some part sourcing links for battery clip and power switch and added some design ideas
2024-05-04 added some markers for future LED positions
    [ctfl-rakete-tht.kicad_pcb]
2024-05-04 added symbols for battery clip, ATtiny, power switch and one LED
    [ctfl-rakete-tht.kicad_sch]
2024-05-07 created combo footprint for 0805 SMD or 5mm standard LED
2024-05-07 added LED symbols and a bunch of wires and replaced ATTINY85 with ATTINY212 symbol
    [ctfl-rakete-tht.kicad_sch]
2024-05-10 added new kicad autosave file to gitignore
2024-05-10 added UPDI header and associated R and C
    [ctfl-rakete-tht.kicad_sch]
2024-05-10 added pwr_flags to satisfy ERC in schematic
    [ctfl-rakete-tht.kicad_sch]
2024-05-10 reimported graphics into layout scaled to 139 percent for optimum 100x100 mm PCB limit usage (the original size was too slim for the battery clip)
    [ctfl-rakete-tht.kicad_pcb]
2024-05-10 optimized polarity marking placement on LED footprint
2024-05-10 moved LED footprints to their locations
    [ctfl-rakete-tht.kicad_pcb]
2024-05-10 removed some solder mask from the bottom side where the LEDs shall shine
    [ctfl-rakete-tht.kicad_pcb]
2024-05-10 optimized switch connections
    [ctfl-rakete-tht.kicad_pcb, ctfl-rakete-tht.kicad_sch]
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2024-05-10 placed other components and started routing
    [ctfl-rakete-tht.kicad_pcb]
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2024-05-11 finished layout for revision A
    [ctfl-rakete-tht.kicad_pcb, ctfl-rakete-tht.kicad_sch]
2024-05-14 replaced in-flame LED footprints with 0805-only version and reoriented them
    [ctfl-rakete-tht.kicad_pcb, ctfl-rakete-tht.kicad_sch]
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2024-05-17 added hanging wire solder points and updated renders
    [ctfl-rakete-tht.kicad_pcb, ctfl-rakete-tht.kicad_sch]
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2024-05-25 added PDF plot of schematics
    [ctfl-rakete-tht.kicad_sch]
2024-05-25 added fabrication files
    [ctfl-rakete-tht-B_Cu.gbl, ctfl-rakete-tht-B_Mask.gbs, ctfl-rakete-tht-B_Paste.gbp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]
2024-05-28 added a second decoupling capacitor with 1 uF to the Controller supply
    [ctfl-rakete-tht-B_Cu.gbl, ctfl-rakete-tht-B_Mask.gbs, ctfl-rakete-tht-B_Paste.gbp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]
2024-05-30 updated to use design with new name 'Chaos Computer Club Flensburg E.V.'
    [ctfl-rakete-tht-B_Cu.gbl, ctfl-rakete-tht-B_Mask.gbs, ctfl-rakete-tht-B_Paste.gbp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]
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2024-06-01 added sourcing links to mouser.de for the remaining parts
2024-06-01 added and updated meta data of schematics and layout pages
    [ctfl-rakete-tht.kicad_pcb, ctfl-rakete-tht.kicad_sch]
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2024-06-10 close #1: replaced F.Mask in layout with revised geometry as per previous commit and extended B.Mask around ATtiny212 label
    [ctfl-rakete-tht.kicad_pcb]
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2024-06-24 WIP: added new still incomplete footprint for horizontal SMD pin header
2024-06-24 WIP: started work on changing the programming header footprint to a more suitable 3 pin variant
    [ctfl-rakete-tht.kicad_pcb, ctfl-rakete-tht.kicad_sch]
2024-06-24 added a loop to Edge.Cuts so that people can clip the pcb to a lanyard
    [ctfl-rakete-tht.kicad_pcb]
2024-06-24 close #3: replaced old programming header with a 1x3 horizontal SMD pin socket footprint (don't let the 3D model of it fool you)
    [ctfl-rakete-tht-B_Cu.gbl, ctfl-rakete-tht-B_Mask.gbs, ctfl-rakete-tht-B_Paste.gbp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]
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2024-06-24 corrected slightly embarassing typo...
    [defaultFirmware.ino]
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2024-06-25 added logo script to mask and silkscreen layer so that it is more legible and added a placeholder for JLCPCBs order number
    [ctfl-rakete-tht-B_Cu.gbl, ctfl-rakete-tht-B_Mask.gbs, ctfl-rakete-tht-B_Paste.gbp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]
2024-06-25 changed revision marking to Rev.B
    [ctfl-rakete-tht-B_Cu.gbl, ctfl-rakete-tht-B_Mask.gbs, ctfl-rakete-tht-B_Paste.gbp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]
2024-07-15 exchanged mouser reference to battery clip for a better one that is a little cheaper and currently more available
2025-03-02 added photos for assembly manual and started work on german assembly manual
2025-03-06 added photo montage for tht-LED with uC mixed build
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2026-01-05 added current consumption traces for Li-Ion voltage range on default firmware
    Measured with Rhode&Schwarz NGC103 lab PSU
    [2026-01-05 Rakede on LiIon 4V2 fast.CSV, 2026-01-05 Rakede on LiIon.CSV]
2026-01-09 changed animation timing in defaultFirmware.ino to 'Leuchtturm Kalkgrund'
    see https://www.deutsche-leuchtfeuer.de/ostsee/kalkgrund.html
2026-01-09 reworked defaultFirmware.ino to support global dimming
    [defaultFirmware.ino]
2026-01-10 fixed bug where micros() was overflowing but nextFrame in animateFlame() was not
    [defaultFirmware.ino]
2026-01-10 added global dimming in relation to supply voltage to keep light output and current consumption nearly constant above a certain voltage
2026-01-26 added discharge recording of a LIR2032 supplying the current firmware
2026-01-28 added recording of LIR2032 discharge cycle with enabled under voltage lockout (MCU shutdown below 2.8V)
    The test failled because apparentlly the MCU did correctly shut down at 2.8 V but it held the GPIO states (all LEDs on) which should not be the case.
2026-01-28 Added LED shutoff before going to sleep on undervoltage and fixed GPIO initiallization
    [defaultFirmware.ino]
2026-01-28 reduced ADC reference to 1.5 V so that 2.4 V can actually be detected
2026-01-29 reduced voltage dependant global dimming brightness
    from 200 to 80
2026-01-30 added recording of LIR2032H discharge cycle with enabled under voltage lockout that completely works
    with the reduced global brightness from ed443e1, this now yields a run time of about 7.5 hours
2026-01-30 Rename battery name in recording from LIR2032 to LIR2032H
2026-02-03 added comments about different current consumptions to defaultFirmware.ino
2026-02-20 idea for fixing flame freeze bug
    The frame index for animateFlame() is now derived from nowUs argument by dividing by FRAMETIME_US instead of counting nest frame start time up by FRAMETIME_US when micros() returns a lager value.
    This should fix the flame animation freeze that occurred on some micros() overflows.
    [defaultFirmware.ino]
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

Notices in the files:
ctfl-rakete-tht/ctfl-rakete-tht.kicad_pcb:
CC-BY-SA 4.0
